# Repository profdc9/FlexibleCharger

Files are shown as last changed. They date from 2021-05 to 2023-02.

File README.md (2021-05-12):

# FlexibleCharger

This is a battery charger based on a commonly-available ATMEGA328P for control and a common TL494 switching power supply IC.  It is intended to be easily and cheaply reproduced, and is for experimentation with different methods of charging batteries.  It is also useful as a power supply.

It is licensed under the Creative Commons CC-BY-SA 4.0, attribution and share-alike clauses.  It is open-source hardware and software created by Daniel Marks.  The schematic, gerber files, and Arduino code is available under open source licenses.

The device is intended to be powered from another unregulated or switching power supply, with up to 30 volts input.  As given in the schematic, the output can be up to 24 volts and 6 amps.  It would be possible to modify the circuit to perhaps allow for up to 28 volts and 15 amps.

It is designed to be used independently of a computer, having a simple user interface of three buttons and a 2-by-16 LCD alphanumeric display.  The software has been created in the Arduino environment to be easily modified and customized.  

WARNING:  Since this device gives you the ability to specify the voltage and/or current you wish to charge with, it is easily possible to damage or blow up batteries with improper configuration.  This is especially true of lithium batteries which can catch fire and be difficult to extinguish.  The author is not responsible for damage or injury resulting from the use of the device, as it is intended for experimentation.

The device must be calibrated before used, with the calibration parameters stored in EEPROM.  To do this, you need a voltmeter, a calibrated resistor with a known resistance from 5 to 10 ohms, and a wire to use as a short circuit load.  The procedure is:

* Choose the "Calibrate" menu options from the main menu.
* Remove any load from the output so that the output is open circuit.
* Press the button and the charger will apply a test voltage to the output terminals.
* Use a voltmeter to measure this voltage and enter it into the charger.
* Connect the calibrated resistor to output.
* Enter the resistance in ohms of the calibrated resistor.
* Press the button and the charger will apply a constant current to the charger terminals.
* Measure the voltage at the terminals of the calibrated resistor at the output.
* Press the button to end applying the current so that the resistor does not get too hot.
* Enter the measured voltage across the resistor terminals.
* Place the shorting wire across the output terminals.
* Press the button and the charger will apply a constant current to the charger terminals.
* After a few seconds, the charger shuts off the current and the calibration is complete.

To charge a battery, one must first enter a charging program.  At the time of this writing, there only two types of charging programs: Constant Voltage/Constant Current and Pulsed Recovery mode.  The "Change Program" is used to select the type of program and the parameters for the program.  There are 12 program banks currently.

* Constant Voltage/Constant Current:  Charge with a maximum constant current until a particular voltage is reached, then hold the voltage constant.  This may be used, for example, to float batteries.  The combination of constant voltage and constant current limits the power delivered to the battery.

* Pulsed Recovery Mode:  This is intended to be a mode that desulfates lead-acid cells.  It has multiple parameters.  Pulsed Voltage/Pulsed Current are the maximum voltage and current to apply during a pulse.  Pulse length is the duration of the current pulse to apply to the battery.  Interval is the time between pulses, which should be much longer than the pulse length so that significant heat does not build up in the battery.  Recovery volts is the voltage that the charger checks for when no current is applied to see if the battery has become sufficiently desulfated for normal charging.  Target volts and trickle charge is the maximum voltage and current to apply when charging after the recovery voltage has been achieved to trickle charge the battery to capacity.

"Execute Program" is used to start a charging program.  The charging programs generally may be aborted by pressing the rightmost button.

"Power supply" is a mode that may be used to use the charger like a constant voltage/constant current power supply.  The current limit is approximate and is intended to prevent short circuits from causing device damage.

Please take care when using this device, as it can potentially cause batteries to burn or explode.  Do not leave batteries unattended when charging.

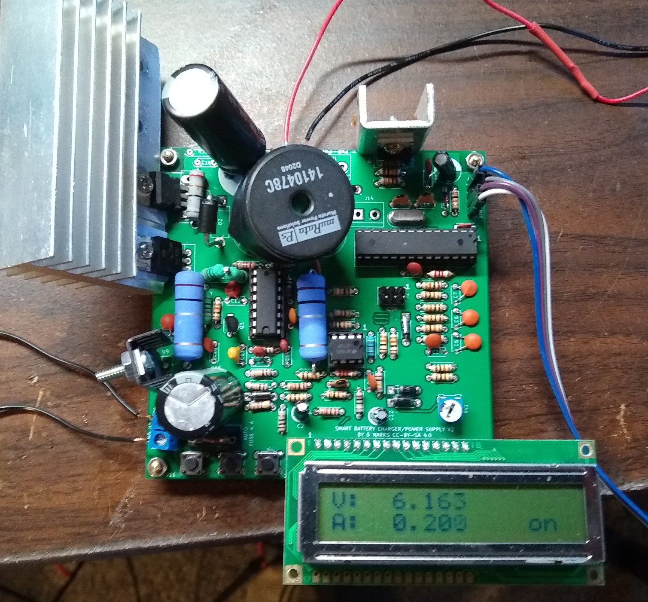
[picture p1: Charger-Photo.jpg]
PCB


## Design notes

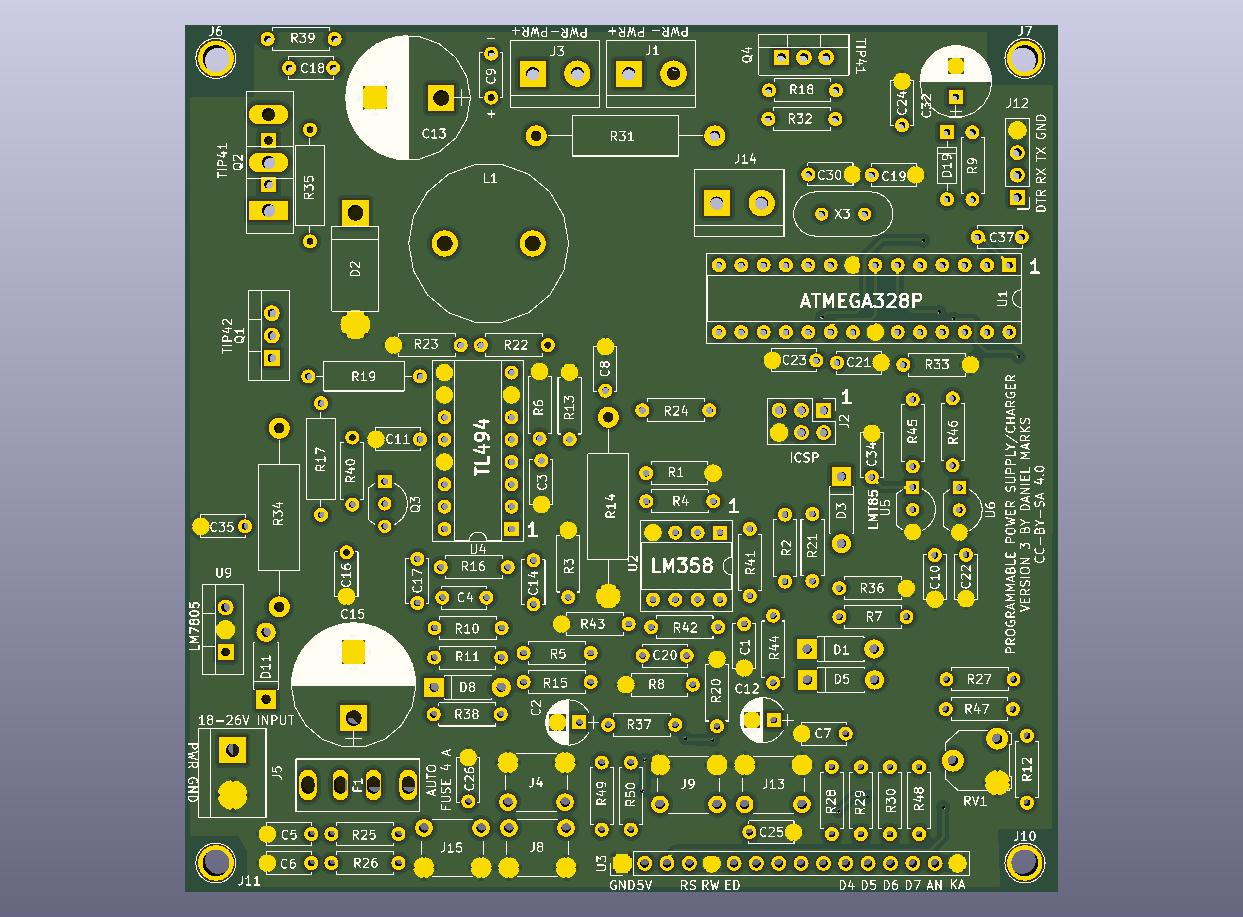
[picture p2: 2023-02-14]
FlexiblePS/FlexiblePS.png

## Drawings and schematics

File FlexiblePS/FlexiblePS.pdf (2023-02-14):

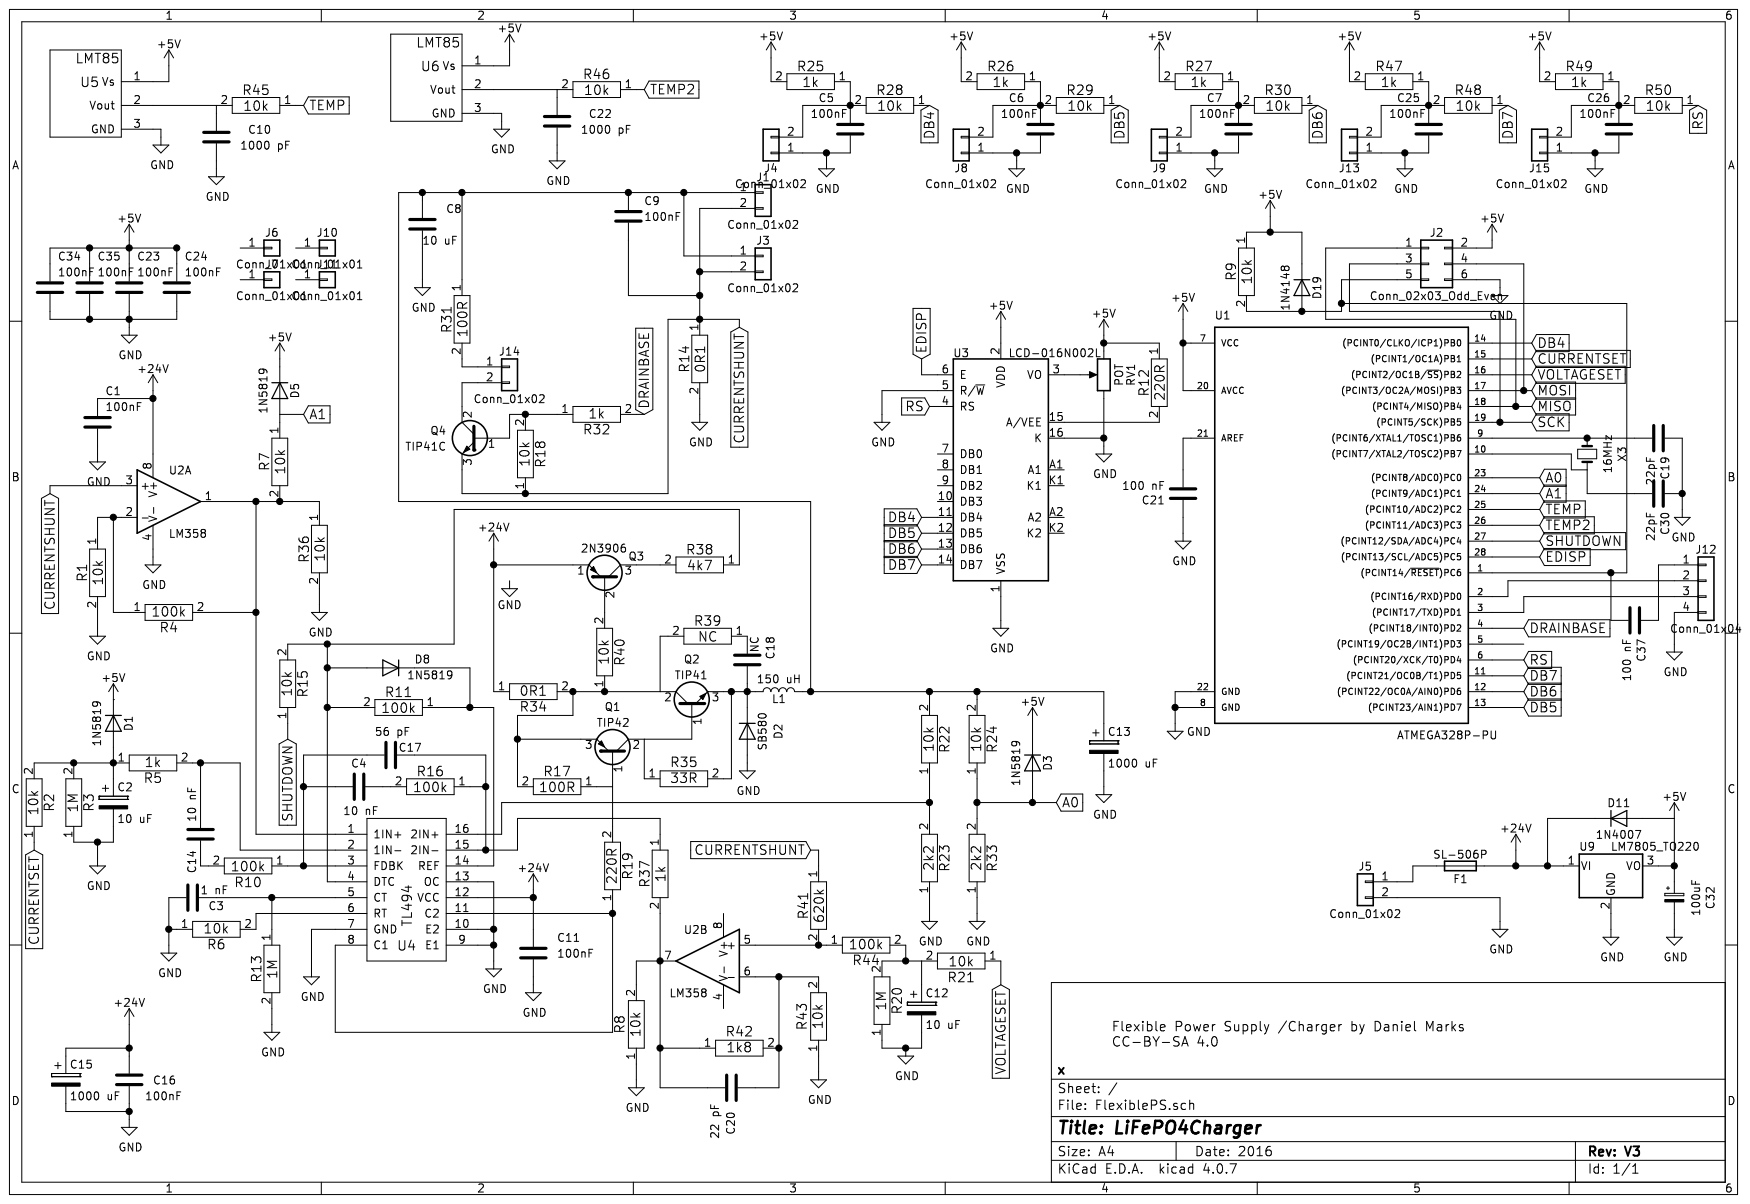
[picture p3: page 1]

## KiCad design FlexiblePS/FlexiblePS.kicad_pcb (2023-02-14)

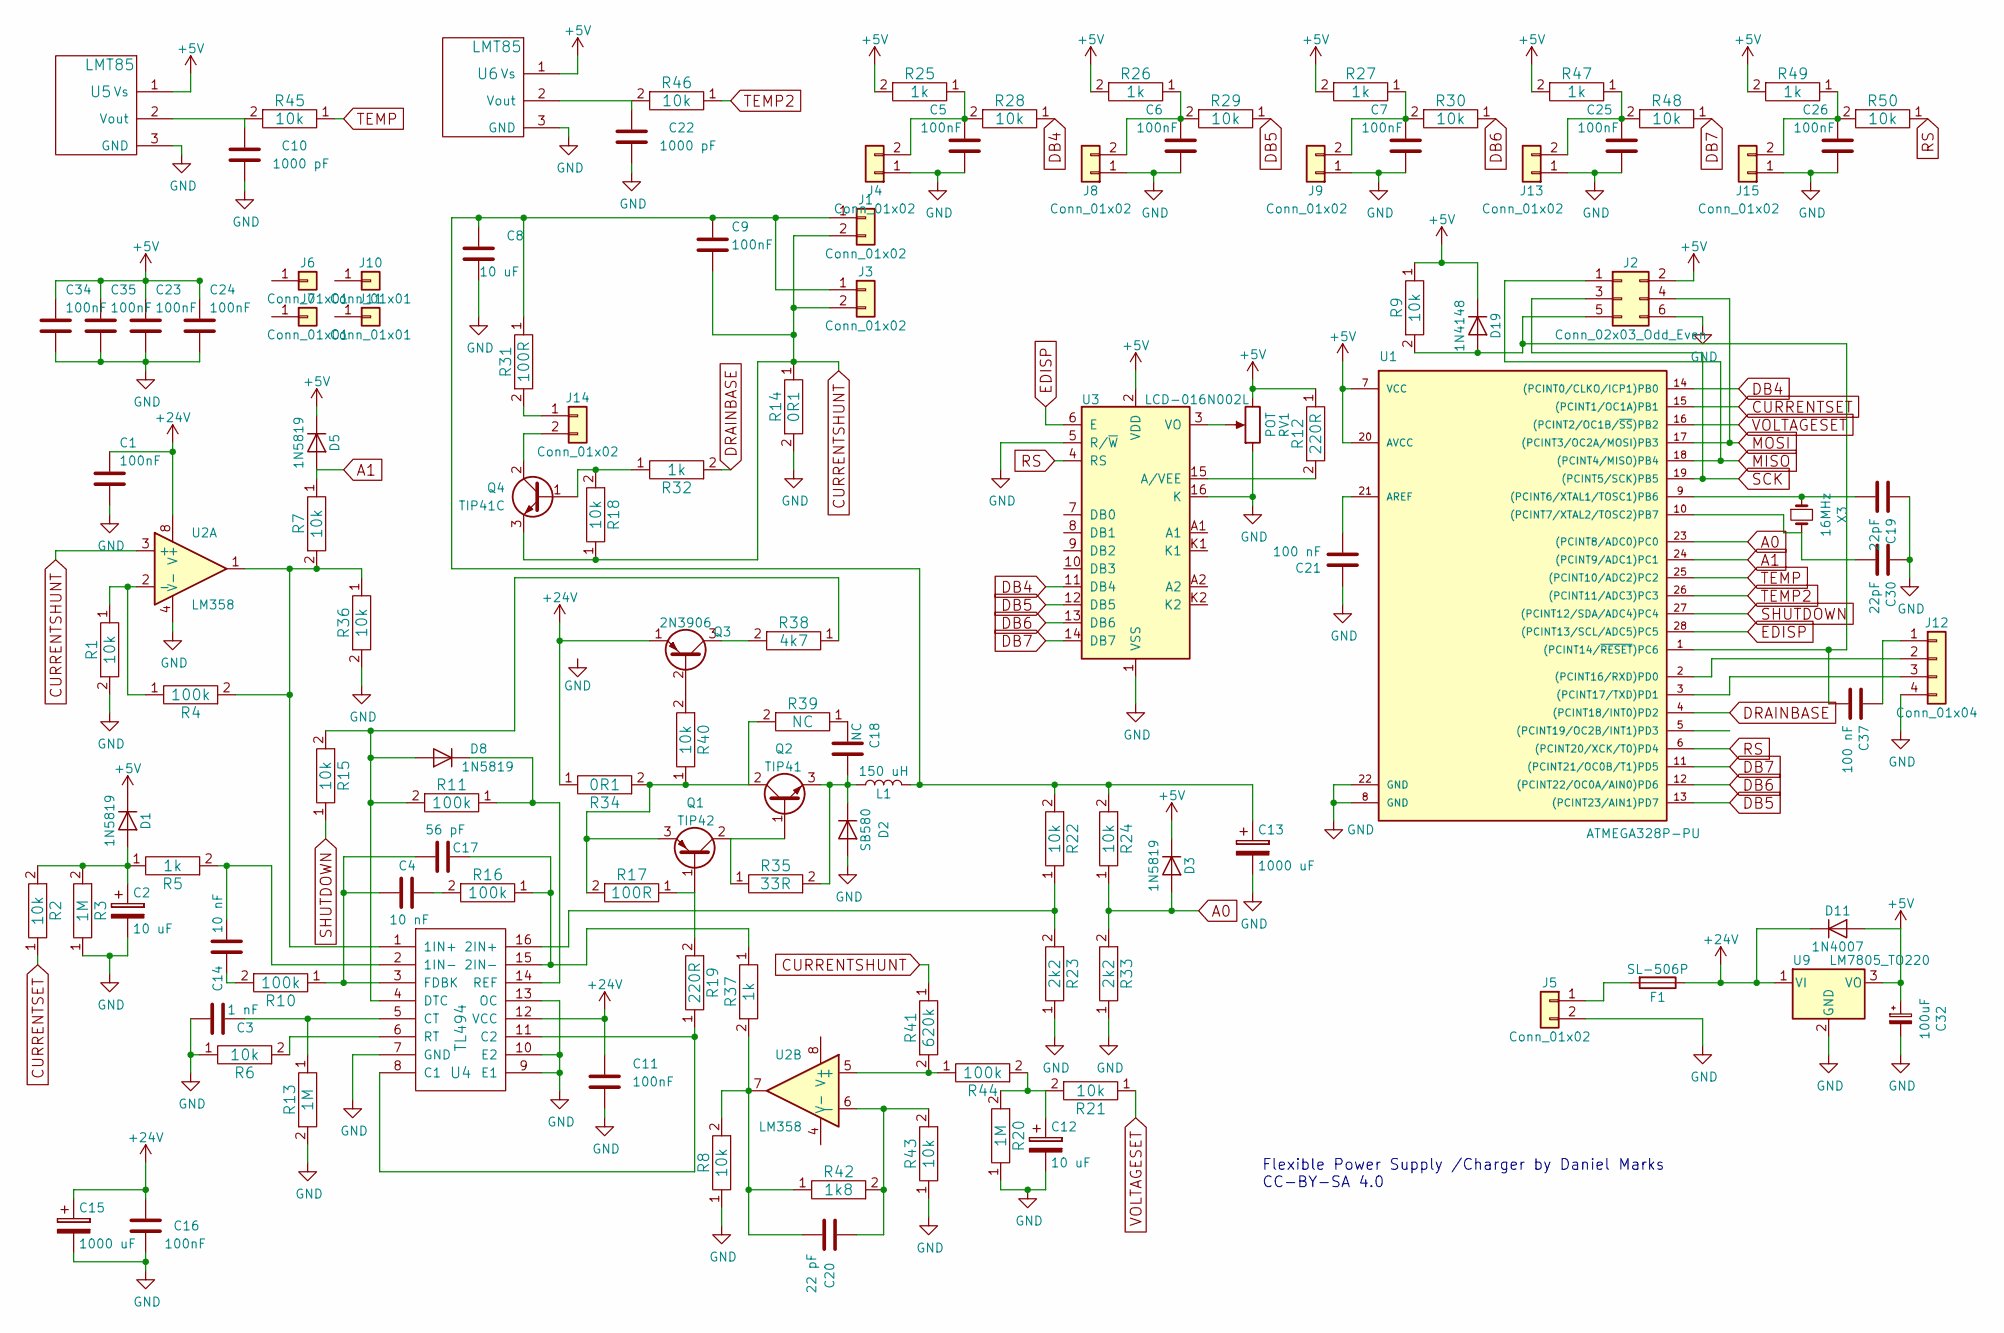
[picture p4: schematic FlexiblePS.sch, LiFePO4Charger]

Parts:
C1, C5, C6, C7, C9, C11, C16, C23, C24, C25, C26, C34, C35: 100nF; C_Disc_D5.0mm_W2.5mm_P5.00mm
C2, C12: 10 uF; CP_Radial_D5.0mm_P2.50mm
C3: 1 nF; C_Disc_D5.0mm_W2.5mm_P5.00mm
C4, C14: 10 nF; C_Disc_D5.0mm_W2.5mm_P5.00mm
C8: 10 uF; C_Disc_D5.0mm_W2.5mm_P5.00mm
C10, C22: 1000 pF; C_Disc_D5.0mm_W2.5mm_P5.00mm
C13, C15: 1000 uF; CP_Radial_D14.0mm_P7.50mm
C17: 56 pF; C_Disc_D5.0mm_W2.5mm_P5.00mm
C18: NC; C_Disc_D5.0mm_W2.5mm_P5.00mm
C19, C30: 22pF; C_Disc_D5.0mm_W2.5mm_P5.00mm
C20: 22 pF; C_Disc_D5.0mm_W2.5mm_P5.00mm
C21, C37: 100 nF; C_Disc_D5.0mm_W2.5mm_P5.00mm
C32: 100uF; CP_Radial_D8.0mm_P3.50mm
D1, D3, D5, D8: 1N5819; D_DO-41_SOD81_P7.62mm_Horizontal
D2: SB580; D_DO-201_P12.70mm_Horizontal
D11: 1N4007; D_DO-41_SOD81_P7.62mm_Horizontal
D19: 1N4148; D_DO-35_SOD27_P7.62mm_Horizontal
F1: SL-506P; SL506Pfuseholder
J1, J3, J5, J14: Conn_01x02; TerminalBlock_bornier-2_P5.08mm
J2: Conn_02x03_Odd_Even; Pin_Header_Straight_2x03_Pitch2.54mm
J4, J8, J9, J13, J15: Conn_01x02; SW_PUSH_6mm_h4.3mm
J6, J7, J10, J11: Conn_01x01; 1pin
J12: Conn_01x04; Pin_Header_Straight_1x04_Pitch2.54mm
L1: 150 uH; L_Radial_D18.0mm_P10.00mm
Q1: TIP42; TO-220-3_Vertical
Q2: TIP41; TO-247_TO-3P_Vertical
Q3: 2N3906; TO-92_Inline_Wide
Q4: TIP41C; TO-220-3_Vertical
R1, R2, R6, R7, R8, R9, R15, R18, R21, R22, R24, R28, R29, R30, R36, R40, R43, R45, R46, R48, R50: 10k; R_Axial_DIN0207_L6.3mm_D2.5mm_P7.62mm_Horizontal
R3, R13, R20: 1M; R_Axial_DIN0207_L6.3mm_D2.5mm_P7.62mm_Horizontal
R4, R10, R11, R16, R44: 100k; R_Axial_DIN0207_L6.3mm_D2.5mm_P7.62mm_Horizontal
R5, R25, R26, R27, R32, R37, R47, R49: 1k; R_Axial_DIN0207_L6.3mm_D2.5mm_P7.62mm_Horizontal
R12: 220R; R_Axial_DIN0207_L6.3mm_D2.5mm_P7.62mm_Horizontal
R14, R34: 0R1; R_Axial_DIN0414_L11.9mm_D4.5mm_P20.32mm_Horizontal
R17: 100R; R_Axial_DIN0309_L9.0mm_D3.2mm_P12.70mm_Horizontal
R19: 220R; R_Axial_DIN0309_L9.0mm_D3.2mm_P12.70mm_Horizontal
R23, R33: 2k2; R_Axial_DIN0207_L6.3mm_D2.5mm_P7.62mm_Horizontal
R31: 100R; R_Axial_DIN0414_L11.9mm_D4.5mm_P20.32mm_Horizontal
R35: 33R; R_Axial_DIN0309_L9.0mm_D3.2mm_P12.70mm_Horizontal
R38: 4k7; R_Axial_DIN0207_L6.3mm_D2.5mm_P7.62mm_Horizontal
R39: NC; R_Axial_DIN0207_L6.3mm_D2.5mm_P7.62mm_Horizontal
R41: 620k; R_Axial_DIN0207_L6.3mm_D2.5mm_P7.62mm_Horizontal
R42: 1k8; R_Axial_DIN0207_L6.3mm_D2.5mm_P7.62mm_Horizontal
RV1: POT; Potentiometer_Triwood_RM-065
U1: ATMEGA328P-PU; DIP-28_W7.62mm_Socket
U2: LM358; DIP-8_W7.62mm_Socket
U3: LCD-016N002L; Pin_Header_Straight_1x16_Pitch2.54mm
U4: TL494; DIP-16_W7.62mm_Socket
U5, U6: LMT85; TO-92_Inline_Wide
U9: LM7805_TO220; TO-220-3_Vertical
X3: 16MHz; Crystal_HC49-U_Vertical

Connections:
+5V: C23.1, C24.1, C32.1, C34.1, C35.1, D1.1 (K), D3.1 (K), D5.1 (K), D11.2 (A), D19.1 (K), J2.2, R9.1, R12.1, R25.2, R26.2, R27.2, R47.2, R49.2, RV1.3, U1.7 (VCC), U1.20 (AVCC), U3.2 (VDD), U5.1 (Vs), U6.1 (Vs), U9.3 (VO)
+24V: C1.1, C11.1, C15.1, C16.1, D11.1 (K), F1.1, Q3.1 (E), R34.1, U2.8 (V+), U4.12 (VCC), U9.1 (VI)
A0: D3.2 (A), R24.1, R33.2, U1.23 ((PCINT8/ADC0)PC0)
A1: D5.2 (A), R7.1, U1.24 ((PCINT9/ADC1)PC1)
CURRENTSET: R2.1, U1.15 ((PCINT1/OC1A)PB1)
CURRENTSHUNT: C9.2, J1.2, J3.2, Q4.3 (E), R14.1, R18.1, R41.1, U2.3 (+)
DB4: R28.1, U1.14 ((PCINT0/CLKO/ICP1)PB0), U3.11 (DB4)
DB5: R29.1, U1.13 ((PCINT23/AIN1)PD7), U3.12 (DB5)
DB6: R30.1, U1.12 ((PCINT22/OC0A/AIN0)PD6), U3.13 (DB6)
DB7: R48.1, U1.11 ((PCINT21/OC0B/T1)PD5), U3.14 (DB7)
DRAINBASE: R32.2, U1.4 ((PCINT18/INT0)PD2)
EDISP: U1.28 ((PCINT13/SCL/ADC5)PC5), U3.6 (E)
GND: C1.2, C2.2, C3.2, C5.2, C6.2, C7.2, C8.2, C10.2, C11.2, C12.2, C13.2, C15.2, C16.2, C19.1, C21.1, C22.2, C23.2, C24.2, C25.2, C26.2, C30.1, C32.2, C34.2, C35.2, D2.2 (A), J2.6, J4.1, J5.2, J8.1, J9.1, J12.4, J13.1, J15.1, R1.2, R3.1, R6.1, R8.1, R13.2, R14.2, R20.1, R23.1, R33.1, R36.2, R43.1, RV1.1, U1.8 (GND), U1.22 (GND), U2.4 (V-), U3.1 (VSS), U3.5 (R/~W), U3.16 (K), U4.7 (GND), U4.9 (E1), U4.10 (E2), U4.13 (OC), U5.3 (GND), U6.3 (GND), U9.2 (GND)
MISO: J2.1, U1.18 ((PCINT4/MISO)PB4)
MOSI: J2.4, U1.17 ((PCINT3/OC2A/MOSI)PB3)
unnamed: C2.1, D1.2 (A), R2.2, R3.2, R5.1
unnamed: C3.1, R13.1, U4.5 (CT)
unnamed: C4.1, R16.2
unnamed: C5.1, J4.2, R25.1, R28.2
unnamed: C6.1, J8.2, R26.1, R29.2
unnamed: C7.1, J9.2, R27.1, R30.2
unnamed: C10.1, R45.2, U5.2 (Vout)
unnamed: C12.1, R20.2, R21.2, R44.2
unnamed: C8.1, C9.1, C13.1, J1.1, J3.1, L1.2, R22.2, R24.2, R31.1
unnamed: C14.1, R10.2
unnamed: C14.2, R5.2, U4.2 (1IN-)
unnamed: C17.1, R16.1, R37.1, U4.15 (2IN-)
unnamed: C4.2, C17.2, R10.1, U4.3 (FDBK)
unnamed: C18.1, D2.1 (K), L1.1, Q2.3 (E), R35.2
unnamed: C18.2, R39.1
unnamed: C19.2, U1.9 ((PCINT6/XTAL1/TOSC1)PB6), X3.1
unnamed: C20.1, R42.2, R43.2, U2.6 (-)
unnamed: C20.2, R8.2, R37.2, R42.1, U2.7
unnamed: C21.2, U1.21 (AREF)
unnamed: C22.1, R46.2, U6.2 (Vout)
unnamed: C25.1, J13.2, R47.1, R48.2
unnamed: C26.1, J15.2, R49.1, R50.2
unnamed: C30.2, U1.10 ((PCINT7/XTAL2/TOSC2)PB7), X3.2
unnamed: C37.1, J12.1
unnamed: C37.2, D19.2 (A), J2.5, R9.2, U1.1 ((PCINT14/~RESET~)PC6)
unnamed: D8.1 (K), R11.1, U4.14 (REF)
unnamed: D8.2 (A), R11.2, R15.2, R38.1, U4.4 (DTC)
unnamed: F1.2, J5.1
unnamed: J12.2, U1.2 ((PCINT16/RXD)PD0)
unnamed: J12.3, U1.3 ((PCINT17/TXD)PD1)
unnamed: J14.1, R31.2
unnamed: J14.2, Q4.2 (C)
unnamed: Q1.1 (B), R17.1, R19.2
unnamed: Q1.2 (C), Q2.1 (B), R35.1
unnamed: Q1.3 (E), Q2.2 (C), R17.2, R34.2, R39.2, R40.1
unnamed: Q3.2 (B), R40.2
unnamed: Q3.3 (C), R38.2
unnamed: Q4.1 (B), R18.2, R32.1
unnamed: R1.1, R4.1, U2.2 (-)
unnamed: R6.2, U4.6 (RT)
unnamed: R12.2, U3.15 (A/VEE)
unnamed: R19.1, U4.8 (C1), U4.11 (C2)
unnamed: R22.1, R23.2, U4.16 (2IN+)
unnamed: R4.2, R7.2, R36.1, U2.1, U4.1 (1IN+)
unnamed: R41.2, R44.1, U2.5 (+)
unnamed: RV1.2, U3.3 (VO)
RS: R50.1, U1.6 ((PCINT20/XCK/T0)PD4), U3.4 (RS)
SCK: J2.3, U1.19 ((PCINT5/SCK)PB5)
SHUTDOWN: R15.1, U1.27 ((PCINT12/SDA/ADC4)PC4)
TEMP: R45.1, U1.25 ((PCINT10/ADC2)PC2)
TEMP2: R46.1, U1.26 ((PCINT11/ADC3)PC3)
VOLTAGESET: R21.1, U1.16 ((PCINT2/OC1B/~SS~)PB2)

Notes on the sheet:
Flexible Power Supply /Charger by Daniel Marks CC-BY-SA 4.0

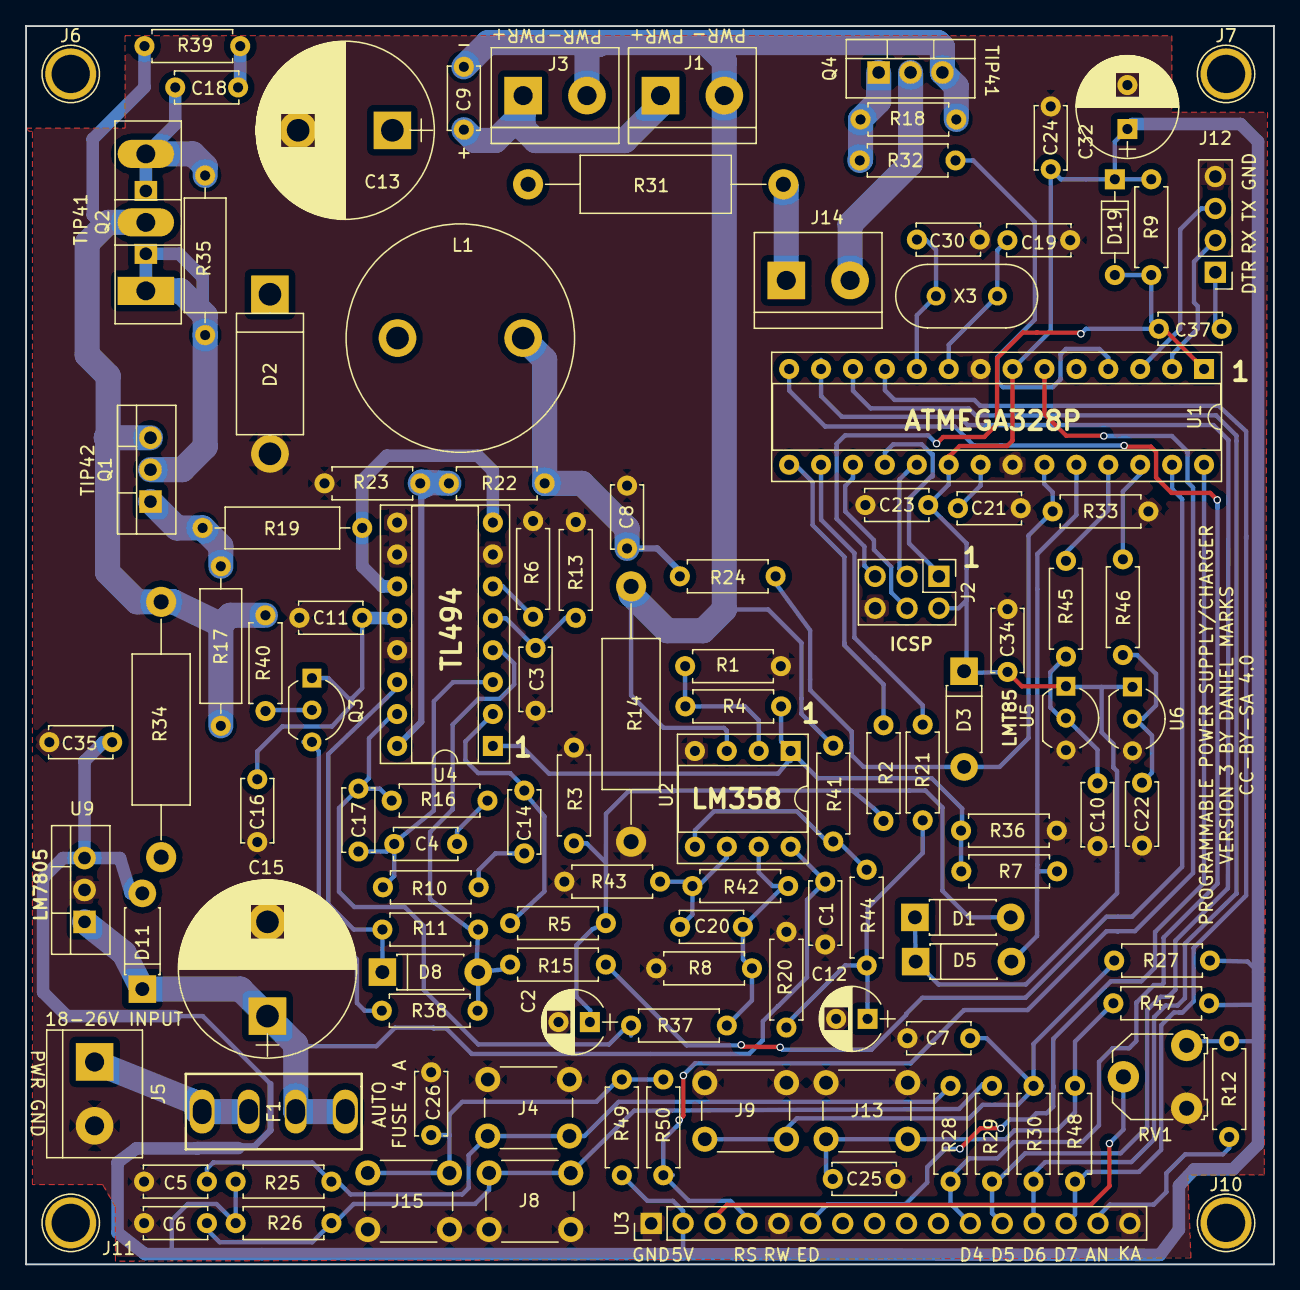
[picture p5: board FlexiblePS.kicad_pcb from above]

Board: 2 copper layers, 99.3 x 98.6 mm, 118 parts (0 on the bottom side), 67 nets.

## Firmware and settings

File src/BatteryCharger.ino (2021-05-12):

#include <Arduino.h>
#include <SPI.h>
#include <Wire.h>
#include <EEPROM.h>
#include <LiquidCrystal.h>

#include "mini-printf.h"

#define SHUTDOWN_CNTRL 4

#define VOLTAGESET 10
#define CURRENTSET 9
#define DRAINBASE 5
#define VOLTAGEADC A0
#define CURRENTADC A1

#define BUTTON1 6
#define BUTTON2 7
#define BUTTON3 8

#define ARDUINORX 1
#define ARDUINOTX 0

#define NUM_BUTTONS 3

const uint8_t buttonPin[NUM_BUTTONS] = {BUTTON1, BUTTON2, BUTTON3};
static uint8_t constStateButton[NUM_BUTTONS];
volatile uint8_t curStateButton[NUM_BUTTONS];
volatile bool pushedButton[NUM_BUTTONS];

#define LCD_EDISP A2
#define LCD_RS A3
#define LCD_DB4 A4
#define LCD_DB5 A5
#define LCD_DB6 2
#define LCD_DB7 3

LiquidCrystal lcd(LCD_RS, LCD_EDISP, LCD_DB4, LCD_DB5, LCD_DB6, LCD_DB7);

#define EE_STRUCT_ADDRESS 0x00
#define VALID_CALIB_MAGIC 0xC001ACE5

#define EE_CHARGE_PROGRAM_STRUCT 0x100u
#define EE_CHARGE_PROGRAM_SEPARATION 0x80u
#define EE_NUMBER_OF_CHARGE_PROGRAMS 12
#define VALID_PROGRAM_MAGIC 0xf001400b

typedef enum _charge_program_type
{
  CONSTANT_VOLTAGE_CONSTANT_CURRENT = 0,
  PULSED_RECOVERY_MODE = 1
} charge_program_type;

const char *program_type_list[]= { "CV/CC", "Pulsed Recovery", NULL };

typedef struct _program_constant_voltage_constant_current
{
  uint16_t constant_voltage;
  uint16_t constant_current;
} program_constant_voltage_constant_current;
  
typedef struct _program_pulsed_recovery_mode
{
  uint16_t pulse_voltage;
  uint16_t pulse_current;
  uint16_t pulse_length;
  uint16_t pulse_interval;
  uint16_t recovery_voltage;
  uint16_t target_voltage;
  uint16_t trickle_charge;
} program_pulsed_recovery_mode;

typedef union _charge_programs
{
  program_constant_voltage_constant_current cvcc;
  program_pulsed_recovery_mode prm;
} charge_programs;

typedef struct _charge_program_struct
{
  uint32_t valid_program;
  charge_program_type cpt;
  charge_programs cp;
} charge_program_struct;

typedef struct _calibration_struct
{
  uint32_t valid_calib;
  float voltage_dac_scaling;
  float current_dac_scaling;
  float a_cal;
  float b_cal;
  float c_cal;
  float d_cal;
} calibration_struct;

calibration_struct cs;

bool read_charge_program_struct(uint8_t prno, charge_program_struct *cps)
{
  if (prno >= EE_NUMBER_OF_CHARGE_PROGRAMS) return false;
  EEPROM.get(EE_CHARGE_PROGRAM_STRUCT + prno * EE_CHARGE_PROGRAM_SEPARATION, *cps);
  return (cps->valid_program == VALID_PROGRAM_MAGIC);
}

bool write_charge_program_struct(uint8_t prno, charge_program_struct *cps)
{
  if (prno >= EE_NUMBER_OF_CHARGE_PROGRAMS) return false;
  cps->valid_program = VALID_PROGRAM_MAGIC;
  EEPROM.put(EE_CHARGE_PROGRAM_STRUCT + prno * EE_CHARGE_PROGRAM_SEPARATION, *cps);
}

bool is_calibration_valid(void)
{
  return cs.valid_calib == VALID_CALIB_MAGIC;
}

bool isButtonDown(uint8_t b)
{
  return !curStateButton[b];
}

void waitButtonUp(uint8_t b)
{
  while (curStateButton[b] == LOW);
  pushedButton[b] = false;
}

bool getPushedButton(uint8_t b)
{
  if (pushedButton[b])
  {
    pushedButton[b] = false;
    return true;
  }
  return false;
}

void clearButtons(void)
{
  for (uint8_t b = 0; b < NUM_BUTTONS; b++)
    pushedButton[b] = false;
}

bool getPushedAndWaitButton(uint8_t b)
{
  bool state = getPushedButton(b);
  if (state)
  {
    waitButtonUp(b);
    clearButtons();
  }
  return state;
}


void debounce_buttons(void)
{
  for (uint8_t b = 0; b < NUM_BUTTONS; b++)
  {
    uint8_t state = digitalRead(buttonPin[b]);
    if (curStateButton[b] != state)
    {
      if ((++constStateButton[b]) >= 20)
      {
        curStateButton[b] = state;
        if (state == LOW) pushedButton[b] = true;
        constStateButton[b] = 0;
      }
    } else constStateButton[b] = 0;
  }
}

volatile uint8_t skipcounter = 0;
volatile uint32_t countv = 0;

ISR(TIMER1_OVF_vect)
{
  skipcounter++;
  if (skipcounter < 16) return;
  skipcounter = 0;
  countv++;
  debounce_buttons();
}

void shutdown_output()
{
  digitalWrite(SHUTDOWN_CNTRL, HIGH);
  analogWrite(VOLTAGESET,0);
  analogWrite(CURRENTSET,0);
}

void output_voltage_current(uint16_t voltage, uint16_t current)
{
  digitalWrite(SHUTDOWN_CNTRL, HIGH);  
  analogWrite(VOLTAGESET,voltage);
  analogWrite(CURRENTSET,current);
  digitalWrite(SHUTDOWN_CNTRL, LOW);  
}

void setup() {
  pinMode(SHUTDOWN_CNTRL, OUTPUT);
  pinMode(VOLTAGESET, OUTPUT);
  pinMode(CURRENTSET, OUTPUT);
  shutdown_output();
  pinMode(DRAINBASE, OUTPUT);
  digitalWrite(DRAINBASE, LOW);
  pinMode(BUTTON1, INPUT);
  pinMode(BUTTON2, INPUT);
  pinMode(BUTTON3, INPUT);
  pinMode(VOLTAGEADC, INPUT);
  pinMode(CURRENTADC, INPUT);

  lcd.begin(16, 2);
  Serial.begin(9600);

  /* Set up FAST PWM, 10-bit */
  noInterrupts();           // disable all interrupts
  TCCR1A = _BV(COM1A1) | _BV(COM1B1) | _BV(WGM11) | _BV(WGM10)  ;
  TCCR1B = _BV(CS10) | _BV(WGM12);
  TIMSK1 |= _BV(TOIE1);  /* enable timer overflow interrupt */
  interrupts();  

  analogReference(DEFAULT);
  EEPROM.get(EE_STRUCT_ADDRESS,cs);
}

void accumulate_voltage_and_current(uint16_t avgs, float *volts, float *current)
{
  uint32_t voltavg = 0;
  uint32_t curavg = 0;
  float avgfloat = avgs;
  while (avgs>0)
  {
    avgs--;
    voltavg += analogRead(VOLTAGEADC);
    curavg += analogRead(CURRENTADC);
  }
  *volts = ((float)voltavg)/avgfloat;
  *current = ((float)curavg)/avgfloat;
}

uint8_t do_menu(const char *items[], const char *prompt, uint8_t item)
{
  for (;;)
  {
    lcd.clear();
    lcd.print(prompt);
    lcd.setCursor(0, 1);
    lcd.print(items[item]);
    for (;;)
    {
      if ((getPushedButton(0)) && (item > 0)) 
      {
        item--;
        break;
      }
      if ((getPushedButton(1)) && (items[item+1] != NULL))
      {
        item++;
        break;
      }
      if (getPushedAndWaitButton(2))
      {
        return item;
      }
    }
  }
}

uint32_t inc_number(uint8_t consec)
{
  if (consec > 45) return 30000;
  if (consec > 40) return 10000;
  if (consec > 35) return 3000;
  if (consec > 30) return 1000;
  if (consec > 25) return 300;
  if (consec > 20) return 100;
  if (consec > 15) return 30;
  if (consec > 10) return 10;
  if (consec > 5) return 3;
  return 1; 
}

uint32_t enter_number(uint32_t n, uint32_t minimum_number, uint32_t maximum_number, const char *format, uint16_t divisor, const char *prompt)
{
  char s[20];
  uint8_t consec = 0;
  for (;;)
  {
    lcd.clear();
    lcd.print(prompt);
    mini_snprintf(s,sizeof(s)-1,format,n/divisor,n%divisor);
    lcd.setCursor(0,1);
    lcd.print(s);
    delay(consec ? 250 : 500);
    for (;;) {
        if (isButtonDown(0))
        {
          if (n < (minimum_number + inc_number(consec)))
            n = minimum_number;
          else
            n -= inc_number(consec);
          if (consec < 50) consec++;
          break;
        } else if (isButtonDown(1))
        {
          if (n >= (maximum_number - inc_number(consec)))
            n = maximum_number;
          else
            n += inc_number(consec);
          if (consec < 50) consec++;
          break;
        } else if (isButtonDown(2)) 
        {
          waitButtonUp(2);
          clearButtons();
          return n;
        } 
        consec = 0;
    }
  }
}

bool show_messages(const char *message1, const char *message2)
{
    
  clearButtons();
  lcd.clear();
  lcd.print(message1);
  lcd.setCursor(0,1);
  lcd.print(message2);
  for (;;) {
     if (getPushedButton(0)) 
     {
       waitButtonUp(0);
       return false;
     }  
     if (getPushedButton(2))
     {
       waitButtonUp(2);
       return true;
     }  
  }
}

bool go_or_abort(const char *message)
{
  return show_messages(message, "Rt cont,lft abrt");
}

#define OPEN_CIRCUIT_DAC_VOLTAGE_SAMPLE 512
#define OPEN_CIRCUIT_DAC_CURRENT_SAMPLE 100
#define LOAD_CIRCUIT_DAC_VOLTAGE_SAMPLE 256
#define LOAD_CIRCUIT_DAC_CURRENT_SAMPLE 1023
#define SHORT_CIRCUIT_DAC_VOLTAGE_SAMPLE 100
#define SHORT_CIRCUIT_DAC_CURRENT_SAMPLE 512
#define NUMBER_OF_AVERAGES 256
#define SENSE_RESISTOR_VALUE_OHMS (0.1f)

void calculate_load_current_and_voltage(calibration_struct *ns, float voltsamp, float currentsamp, float *truevolts, float *truecurrent)
{
  *truevolts = ns->a_cal * voltsamp + ns->b_cal * currentsamp;
  *truecurrent = ns->c_cal * voltsamp + ns->d_cal * currentsamp;
}

void do_calibrate(void)
{
  calibration_struct ns;

  float resistance_load;
  float open_ckt_voltage;
  float load_ckt_voltage;

  float open_voltage, open_current;
  float load_voltage, load_current;
  float short_voltage, short_current;
  float actual_voltage, actual_current;

  if (!go_or_abort("Open ckt test"))
    return;
  output_voltage_current(OPEN_CIRCUIT_DAC_VOLTAGE_SAMPLE,  OPEN_CIRCUIT_DAC_CURRENT_SAMPLE);
  delay(1000);
  accumulate_voltage_and_current(NUMBER_OF_AVERAGES, &open_voltage, &open_current);
  if (!go_or_abort("Measure voltage and enter"))
  {
    shutdown_output();
    return;
  }
  shutdown_output();
  open_ckt_voltage = ((float)enter_number(1343, 0, 3000, "%02lu.%02lu", 100, "Enter open ckt voltage"))*0.01f;
  ns.voltage_dac_scaling = ((float)OPEN_CIRCUIT_DAC_VOLTAGE_SAMPLE) / open_ckt_voltage;

  resistance_load = ((float)enter_number(5111, 1000, 30000, "%02lu.%03lu", 1000, "Load resistance"))*0.001f;
  if (!go_or_abort("Load test"))
    return;
  output_voltage_current(LOAD_CIRCUIT_DAC_VOLTAGE_SAMPLE, LOAD_CIRCUIT_DAC_CURRENT_SAMPLE);
  delay(1000);
  accumulate_voltage_and_current(NUMBER_OF_AVERAGES, &load_voltage, &load_current);
  if (!go_or_abort("Measure voltage and enter"))
  {
    shutdown_output();
    return;
  }
  shutdown_output();  
  load_ckt_voltage = ((float)enter_number(676, 0, 3000, "%02lu.%02lu", 100, "Enter load ckt voltage"))*0.01f;

  float divisor = load_current * open_voltage - open_current * load_voltage;
  ns.a_cal = (load_current * open_ckt_voltage - open_current * load_ckt_voltage) / divisor;
  ns.b_cal = (open_voltage * load_ckt_voltage - load_voltage * open_ckt_voltage) / divisor;
  ns.c_cal = -open_current * load_ckt_voltage / (divisor * resistance_load);
  ns.d_cal = open_voltage * load_ckt_voltage / (divisor * resistance_load);

  if (!go_or_abort("Short test"))
    return;

  output_voltage_current(SHORT_CIRCUIT_DAC_VOLTAGE_SAMPLE, SHORT_CIRCUIT_DAC_CURRENT_SAMPLE);
  delay(1000);
  accumulate_voltage_and_current(NUMBER_OF_AVERAGES, &short_voltage, &short_current);
  shutdown_output();  
  calculate_load_current_and_voltage(&ns, short_voltage, short_current, &actual_voltage, &actual_current);

  ns.current_dac_scaling = ((float)(SHORT_CIRCUIT_DAC_CURRENT_SAMPLE)) / actual_current;  
  ns.valid_calib = VALID_CALIB_MAGIC;
  
  EEPROM.put(EE_STRUCT_ADDRESS, ns);
  cs = ns;
  go_or_abort("Calib finished");
}

bool check_calibration(void)
{
  if (!is_calibration_valid())
  {
     show_messages("No calibration","Press left button");
     return false;
  }
  return true;
}

#define VOLTAGE_LIMITED_DAC_VOLTAGE_SAMPLE 512
#define VOLTAGE_LIMITED_DAC_CURRENT_SAMPLE 1023

#define CURRENT_LIMITED_DAC_VOLTAGE_SAMPLE 1023
#define CURRENT_LIMITED_DAC_CURRENT_SAMPLE 512

void string_float(char *s, size_t n, const char *format, float f)
{
  char sn=' ';
  if (f<0)
  {
    f=-f;
    sn='-';
  }
  mini_snprintf(s,n,format,sn,(int16_t)f,(uint16_t)((f-floor(f))*1000.0f));
}

void display_voltage_and_current(float actual_voltage, float actual_current)
{
   char s[20];
   string_float(s,sizeof(s)-1,"V: %c%d.%03u",actual_voltage);
   lcd.clear();
   lcd.print(s);
   string_float(s,sizeof(s)-1,"A: %c%d.%03u",actual_current);
   lcd.setCursor(0,1);
   lcd.print(s);  
}

void acquire_and_display_voltage_current(void)
{
   float test_voltage, test_current;
   float actual_voltage, actual_current;
    
   accumulate_voltage_and_current(NUMBER_OF_AVERAGES, &test_voltage, &test_current);
   calculate_load_current_and_voltage(&cs, test_voltage, test_current, &actual_voltage, &actual_current);
   display_voltage_and_current(actual_voltage, actual_current);
}

void do_test_load(void)
{
  float test_voltage, test_current;
  float actual_voltage, actual_current;
  char s[20];
  
  if (!check_calibration()) return;
  if (!go_or_abort("Attach test load"))
    return;

  output_voltage_current(VOLTAGE_LIMITED_DAC_VOLTAGE_SAMPLE,  VOLTAGE_LIMITED_DAC_CURRENT_SAMPLE);
  delay(2500);  
  accumulate_voltage_and_current(NUMBER_OF_AVERAGES, &test_voltage, &test_current);
  shutdown_output();
 
  calculate_load_current_and_voltage(&cs, test_voltage, test_current, &actual_voltage, &actual_current);

  display_voltage_and_current(actual_voltage, actual_current);
  clearButtons();
  while (!getPushedAndWaitButton(2));
 
  output_voltage_current(CURRENT_LIMITED_DAC_VOLTAGE_SAMPLE, CURRENT_LIMITED_DAC_CURRENT_SAMPLE);
  delay(2500);  
  accumulate_voltage_and_current(NUMBER_OF_AVERAGES, &test_voltage, &test_current);
  shutdown_output();

  calculate_load_current_and_voltage(&cs, test_voltage, test_current, &actual_voltage, &actual_current);
 
  display_voltage_and_current(actual_voltage, actual_current);
  clearButtons();
  while (!getPushedAndWaitButton(2));
}

bool set_output_voltage_current(float voltage, float current, bool ignoremax = false)
{
   float dac_voltage = cs.voltage_dac_scaling * voltage;
   float dac_current = cs.current_dac_scaling * current;
   if (ignoremax)
   {
     if (dac_voltage > 1023.0f) dac_voltage = 1023.0f;
     if (dac_current > 1023.0f) dac_current = 1023.0f;
   } else if ((dac_voltage > 1023.0f) || (dac_current > 1023.0f)) return false;
   output_voltage_current((uint16_t) dac_voltage, (uint16_t) dac_current);
   return true;
}

void do_power_supply(void)
{
  float set_voltage = 0.0f;
  float set_current;
  bool output_off = false;
  uint32_t last_update = 0;

  if (!check_calibration()) return;
  for (;;)
  {
    if (set_voltage == 0.0f)
    {
       shutdown_output();
       set_voltage = ((float)enter_number(0, 0, 3000, "%02lu.%02lu", 100, "Set voltage"))*0.01f;
       set_current = ((float)enter_number(0, 0, 3000, "%02lu.%02lu", 100, "Set current"))*0.01f;
       if (!set_output_voltage_current(set_voltage, set_current))
       {
         show_messages("Current too high","Press left button");
         set_voltage = 0.0f;
         continue;
       }
       clearButtons();
    }
    if (getPushedAndWaitButton(0))
    {
       set_voltage = 0.0f;
       continue;
    }
    if (getPushedAndWaitButton(1))
    {
       if (output_off)
       {
           set_output_voltage_current(set_voltage, set_current);
           output_off = false;
       } else
       {
          shutdown_output();
          output_off = true;
       }
    } 
    if (getPushedAndWaitButton(2))
    {
       shutdown_output();
       break;
    }
    uint32_t current_update = millis();
    if ((current_update - last_update)>100)
    {
      last_update = current_update;
      if (output_off)
      {
        lcd.clear();
        lcd.print("Output off");
        lcd.setCursor(0,1);
        lcd.print("Middle button on");       
      } else
      {
        acquire_and_display_voltage_current();
      }
    }
  }
}

uint8_t select_program(void)
{
  uint8_t current_program = 0;
  charge_program_struct cps;
  for (;;) 
  {
    bool valid = read_charge_program_struct(current_program, &cps);
    lcd.clear();
    lcd.print("Select #");
    lcd.print(current_program+1);
    lcd.print(":");
    lcd.setCursor(0,1);
    lcd.print(valid ? program_type_list[cps.cpt] : "Empty list");
    for (;;)
    {
      if (getPushedAndWaitButton(0))
      {
        if (current_program > 0) current_program--;
        break;
      }
      if (getPushedAndWaitButton(1))
      {
        if (current_program < (EE_NUMBER_OF_CHARGE_PROGRAMS-1)) current_program++;
        break;
      }
      if (getPushedAndWaitButton(2))
        return current_program;
    }
  }
}

void do_execute_constant_voltage_constant_current(charge_program_struct *cps)
{
  bool output_off = false;
  uint32_t last_update = 0;
  
  float target_voltage_max = cps->cp.cvcc.constant_voltage * 0.01f;
  float target_voltage_min = target_voltage_max * 0.99f;
  float target_voltage_overshoot = target_voltage_max * 1.1f;

  float target_current = cps->cp.cvcc.constant_current * 0.01f;
  
  float test_voltage, test_current;
  float actual_voltage, actual_current;

  float servo_voltage = 0.0f, servo_current = target_current * 1.5f;
  for (;;)
  {
    uint32_t current_update = millis();
    if ((current_update - last_update)>100)
    {
      bool changed = false;
      accumulate_voltage_and_current(NUMBER_OF_AVERAGES, &test_voltage, &test_current);
      calculate_load_current_and_voltage(&cs, test_voltage, test_current, &actual_voltage, &actual_current);
      if (actual_current > target_current)
      {
        servo_voltage *= (0.9f + 0.1f * target_current / actual_current);
        changed = true;
      } else if (actual_voltage > target_voltage_max)
      {
        servo_voltage += 0.1f * (target_voltage_min - actual_voltage);
        changed = true;
      } else if (actual_voltage < target_voltage_min)
      {
        servo_voltage += 0.1f * (target_voltage_max - actual_voltage);
        if (servo_voltage > target_voltage_overshoot)
          servo_voltage = target_voltage_overshoot;
        changed = true;
      }
      
      if ((changed) && (!output_off))
        set_output_voltage_current(servo_voltage, servo_current);  

      last_update = current_update;
#if 0
         char s[20];
      string_float(s,sizeof(s)-1,"SV: %c%d.%03u",servo_voltage);
       lcd.clear();
      lcd.print(s);
       string_float(s,sizeof(s)-1,"SA: %c%d.%03u",servo_current);
      lcd.setCursor(0,1);
      lcd.print(s);  
#endif

      acquire_and_display_voltage_current();
      lcd.setCursor(13,1);
      lcd.print(output_off ? "off" : "on");
    }
    if (getPushedAndWaitButton(1))
    {
      if (output_off)
      {
         output_off = false;
         set_output_voltage_current(servo_voltage, servo_current);       
      } else
      {
         output_off = true;
         shutdown_output();
      }
    }
    if (getPushedAndWaitButton(2))
    { 
      shutdown_output();
      return;
    }
  }
}

void do_execute_pulsed_recovery_mode(charge_program_struct *cps)
{
  uint32_t last_update = 0;
  uint32_t number_of_pulses = 0;  
  bool pulsing = true;
  float test_voltage, test_current;
  float actual_voltage, actual_current;
  float recovery_voltage = cps->cp.prm.recovery_voltage * 0.01f;
  float pulse_voltage = cps->cp.prm.pulse_voltage * 0.01f;
  float pulse_current = cps->cp.prm.pulse_current * 0.01f;
  
  while (pulsing)
  {
    shutdown_output();
    for (uint16_t i=0;i<cps->cp.prm.pulse_interval;i++)
    {
      if (getPushedAndWaitButton(2))
        return;
      delayMicroseconds(1000);
    }
    for (uint8_t i=0;i<5;i++)
    {
      accumulate_voltage_and_current(NUMBER_OF_AVERAGES, &test_voltage, &test_current);
      calculate_load_current_and_voltage(&cs, test_voltage, test_current, &actual_voltage, &actual_current);
      if (actual_voltage < recovery_voltage) break;
      if (i == 4)
        pulsing = false;
    }
    uint32_t current_update = millis();
    if ((current_update - last_update)>100)
    {
      last_update = current_update;
      char s[20];
      string_float(s,sizeof(s)-1,"V: %c%d.%03u",actual_voltage);
      lcd.clear();
      lcd.print(s);
      lcd.setCursor(0,1);
      lcd.print("P: ");
      lcd.print(number_of_pulses);  
    }      
    if (pulsing)
    {
        set_output_voltage_current(pulse_voltage, pulse_current, true);  
        for (uint16_t i=0;i<cps->cp.prm.pulse_length;i++)
        {
          if (getPushedAndWaitButton(2))
          {
            shutdown_output();
            return;
          }
          delayMicroseconds(1000);
        }
        shutdown_output();
    }
    number_of_pulses++;
  }
  set_output_voltage_current(cps->cp.prm.target_voltage * 0.01f, cps->cp.prm.trickle_charge * 0.01f);  
  for (;;)
  {
    uint32_t current_update = millis();
    if ((current_update - last_update)>100)
    {
      last_update = current_update;
      acquire_and_display_voltage_current();
    } 
    if (getPushedAndWaitButton(2))
    {
      shutdown_output();
      return;
    }
  }
}

void do_execute_program(void)
{ 
  if (!check_calibration()) return;
  uint8_t program = select_program();  
  charge_program_struct cps;
  if (!read_charge_program_struct(program, &cps))
  {
     show_messages("Select valid prgm","Press left button");
     return;
  }
  if (!go_or_abort("Execute program?"))
    return;
  switch (cps.cpt)
  {
    case CONSTANT_VOLTAGE_CONSTANT_CURRENT:  do_execute_constant_voltage_constant_current(&cps); break;
    case PULSED_RECOVERY_MODE:  do_execute_pulsed_recovery_mode(&cps); break;
  }
}

void do_edit_constant_voltage_constant_current(charge_program_struct *cps)
{
  cps->cp.cvcc.constant_voltage = enter_number(cps->cp.cvcc.constant_voltage, 0, 3000, "%02lu.%02lu", 100, "Const voltage");
  cps->cp.cvcc.constant_current = enter_number(cps->cp.cvcc.constant_current, 0, 3000, "%02lu.%02lu", 100, "Const current");
}
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
void loop() {
  uint8_t item;
  item = do_menu(main_menu_items,"Battery charger menu",0);
  switch (item)
  {
    case 0: do_execute_program();
            break;
    case 1: do_power_supply();
            break;
    case 2: do_change_program();
            break;
    case 3: do_calibrate();
            break;
    case 4: do_test_load();
            break;
  }
}

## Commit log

2021-03-09 Added important shutdown feature
    [LiFePO4smartcharger-B.Cu.gbr, LiFePO4smartcharger-B.Mask.gbr, LiFePO4smartcharger-B.Paste.gbr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]
2021-03-09 Changed to pulse to pulse shut off
    [LiFePO4smartcharger-B.Cu.gbr, LiFePO4smartcharger-B.Mask.gbr, LiFePO4smartcharger-B.Paste.gbr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]
2021-03-09 Oops moved resistor in TIP42
    [LiFePO4smartcharger-B.Cu.gbr, LiFePO4smartcharger-B.Mask.gbr, LiFePO4smartcharger-B.Paste.gbr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]
2021-03-10 Cleaned up layout
    [LiFePO4smartcharger-B.Cu.gbr, LiFePO4smartcharger-B.Mask.gbr, LiFePO4smartcharger-B.Paste.gbr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]
2021-03-13 Cleaned up the layout more
    [BuckCircuit-CurrentLimiter.sch, BuckCircuit.sch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]
2021-03-13 Updated schematic
    [BuckCircuit-CurrentLimiter.sch]
2021-03-21 A few tweaks
    [BuckCircuit-CurrentLimiter.sch, BuckCircuit.sch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]
2021-03-23 Added compensation for shunt resistor voltage drop
    [LiFePO4smartcharger-B.Cu.gbr, LiFePO4smartcharger-B.Mask.gbr, LiFePO4smartcharger-B.Paste.gbr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]
2021-03-26 JLCPCB 2021-03-26
    [LiFePO4smartcharger-B.Cu.gbr, LiFePO4smartcharger-B.Mask.gbr, LiFePO4smartcharger-B.Paste.gbr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]
2021-04-10 Fixes to allow for larger components
    [LiFePO4smartcharger-B.Cu.gbr, LiFePO4smartcharger-B.Mask.gbr, LiFePO4smartcharger-B.Paste.gbr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]
2021-04-11 Before switching VOLTAGESET CURRENTSET pins
    [LiFePO4smartcharger-B.Cu.gbr, LiFePO4smartcharger-B.Mask.gbr, LiFePO4smartcharger-B.Paste.gbr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]
2021-04-13 JLCPCB order 2021-04-11
    [LiFePO4smartcharger-B.Cu.gbr, LiFePO4smartcharger-B.Mask.gbr, LiFePO4smartcharger-B.Paste.gbr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]
2021-05-12 Removed on-board RF filter inductor
    [LiFePO4smartcharger-B.Cu.gbr, LiFePO4smartcharger-B.Mask.gbr, LiFePO4smartcharger-B.Paste.gbr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]
2021-07-13 Added spot for LM35 temperature sensor
    [LiFePO4smartcharger-B.Cu.gbr, LiFePO4smartcharger-B.Mask.gbr, LiFePO4smartcharger-B.Paste.gbr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]
2022-08-30 Changed temperature sensor interface
    [LiFePO4smartcharger-B.Cu.gbr, LiFePO4smartcharger-B.Mask.gbr, LiFePO4smartcharger-B.Paste.gbr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]
2023-02-14 Changed to use 5 buttons
    [LiFePO4smartcharger-B.Cu.gbr, LiFePO4smartcharger-B.Mask.gbr, LiFePO4smartcharger-B.Paste.gbr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]
2023-02-14 Renamed project to FlexiblePS
    [FlexiblePS.kicad_pcb, FlexiblePS.sch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]
